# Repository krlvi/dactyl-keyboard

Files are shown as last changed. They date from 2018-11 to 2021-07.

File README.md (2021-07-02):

lfkdsj
# Dactyl Marshmallow
The Dactyl is a parameterized, split-hand, concave, columnar, ergonomic keyboard, originally written by Matt Adereth. See [his README](https://github.com/adereth/dactyl-keyboard#readme) for general info. Here's what's different about mine:

* Round, marshmallowy sides and bottom, in contrast to adereth's minimalist squarish shape.
* (In theory) more configurability, like for different numbers of rows and columns. The thumb is still kind of hardcoded, and there are still hacks.

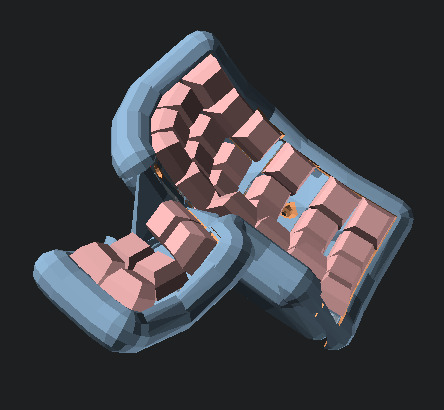
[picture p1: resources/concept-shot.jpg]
A rendering of the whole keyboard, assembled


## Making one of your own

The keyboard is written as a Clojure program, which emits OpenSCAD
code, and as some lower-level OpenSCAD code. Unlike in the original
repository, I don't tend to keep the .scad and .stl files emitted by
the program in the repository and downloadable. Maybe once I get to
1.0.

### Setting up a build environment

* [Install the Clojure runtime](https://clojure.org)
* [Install the Leiningen project manager](http://leiningen.org/)
* [Install OpenSCAD](http://www.openscad.org/)
* Clone https://github.com/adereth/unicode-math; `lein install` it so you have version 0.2.1 ready.

### Building the design

* Run `lein repl`
* Load the file `(load-file "src/dactyl_keyboard/dactyl.clj")`
* This will generate the `things/*.scad` files
* In the `things` directory, `make -k -j8` (it is a GNU makefile). This will build the `.stl` files - and take a half an hour, likely.

### Iterating

* Have an `.scad` file open in OpenSCAD.
* Have this command running: `sh editloop.sh --no-fstl src/dactyl_keyboard/dactyl.clj dactyl-blank-all`
* Make changes to the design, save files, watch as everything is rerun.

There are faster things you can do (keep the REPL open, and do the
`(load-file)` again), and nicer things (CIDER), but this way works for
me and I left it at that.

You can change the definitions of `skip-tags` and `emit-tags` in
`dactyl.clj` to avoid creating some outputs. This can save time if you
are iterating on a part and not the whole keyboard. The keywords you
can put in are just below, in `make-filename`. For example, to avoid
emitting the left half, change the definition of `skip-tags` to:

```
(def skip-tags #{:left})
```

### Printing

Filename convention:

```
[object]-[lr]-[part][piece].stl

e.g.
dm-l-bot01.stl
```

`dm` stands for Dactyl Marshmallow. `lr` is `l` for the left hand, `r`
for the right. Parts are `bot` for bottom, `sid` for sides, `fra` for
frame, and `screw-hole-top`. File names are short so you can tell them
apart on a small LCD display such as you may have on your 3D
printer. There may not be `.stl` files for every numbered piece of the
`bot` part; this is ok. Print one of each piece, and ten
screw-hole-tops. (Don't print `debug-*` files.)  Print also a
`teensy-holder-a` and a `teensy-holder-b`.

Put your controller into the holder, put the two holder pieces
together, and contrive to hold them that way, likely by gluing, but
maybe temporarily with a rubber band. You may not want to stick the
controller in permanently until after you've soldered the wires onto
it.

Numbered pieces of each `dm` part should be glued together. To glue
the bottom, tie pieces together with fishing line, and hold tight
while applying Sci-Grip 4 (acrylic weld, with dichloromethane, danger,
read safety directions) or liquid cyanoacrylate. To glue the frame,
use spring clamps while applying very thin glue such as the foregoing.

Press threaded inserts into the ten screw hole tops using a soldering
iron. Then glue them onto the waffly bits on top of the `bot`
part. Glue the legs on the bottom.

Press a threaded insert into the screw hole in the bottom of one of
the frame pieces. This is where the `teensy-holder` screws in.

Install the connectors into the sides pieces. The USB extension just
screws on; the RJ-11... who knows. Glue?

Once you've installed keyswitches into the frame, done your wiring,
and soldered the wires to the controller, you can screw the frame to
the bottom. Then maybe it's a good time to glue the sides on. Figure
out how you are going to get the last piece in place with all the
other ones already glued, before you start gluing.

This is how I imagine it all goes together. I've still never gotten
all the pieces printed yet! I keep making little changes.

## License

Copyright © 2015, 2018 Matthew Adereth and Jared Jennings

The source code for generating the models (everything excluding the [things/](things/) and [resources/](resources/) directories is distributed under the [GNU AFFERO GENERAL PUBLIC LICENSE Version 3](LICENSE).  The generated models and PCB designs are distributed under the [Creative Commons Attribution-ShareAlike License Version 4.0](LICENSE-models).

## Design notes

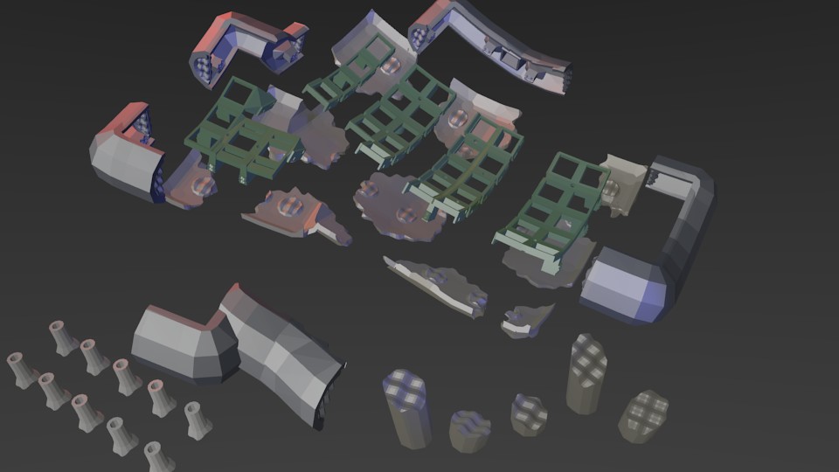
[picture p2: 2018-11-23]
resources/pieces.jpg

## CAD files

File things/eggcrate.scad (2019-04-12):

/** Points of a plane, to which the +x axis is normal
    sy, sz: number of samples in y and z directions.
    dy, dz: size of samples in y and z directions, in units.
    x_offset: location of troughs, in units.
 */
function x_grid_points(sy, sz, dy, dz, x_offset) =
     [for(z=[0:1:sz], y=[0:1:sy])
               [x_offset, y*dy, z*dz]];

/** Points of a wobbly plane, to which the +x axis is normal.
    sy, sz: number of samples in y and z directions.
    dy, dz: size of samples in y and z directions, in units.
    fy, fz: frequency of sine functions in y and z directions -
            given in units, not in samples.
    py, pz: phase in y and z directions - units not samples.
    x_offset: location of midpoint of waves, in units.
    amplitude: depth from peak to trough, in units.
*/
function x_eggcrate_points(sy, sz, dy, dz, fy, fz, py, pz,
                            x_offset, amplitude) =
     [for(z=[0:1:sz], y=[0:1:sy])
               [x_offset+amplitude/4*(0+ /* 2 if you want troughs at 0 */
                                    sin((y*dy+py)*fy*360)+
                                    sin((z*dz+pz)*fz*360)),
                y*dy,
                z*dz]];

/* maybe this *_a, *_b stuff is weak sauce, but i don't know how to
   generate two triangles at a time and end up with a list of [[a1,
   b1, c1], [a2, b2, c2], [a3, b3, c3]] and not some other crazy shape
   which would not work right. for a bit i had [[a1, b1, c1, a2, b2,
   c2], [a3, b3, c3, a4, b4, c4]] and i assume some of those were not
   planar. openscad segfaulted somewhere in cgal's nef_3 module.
   https://github.com/CGAL/cgal/issues/3309
   https://github.com/openscad/openscad/issues/2464
*/

/** Point indices into a grid/eggcrate points vector
    which will result in a series of triangles facing +x.
    The a triangles are only half of them.
    sy, sz: number of samples in y and z directions.
*/
function x_grid_faces_a(sy, sz) =
     [for(z=[0:1:sz-1], y=[0:1:sy-1])
               [y+1+(z+0)*(sy+1),
                y+0+(z+0)*(sy+1),
                y+0+(z+1)*(sy+1)]];

/** Point indices into a grid/eggcrate points vector
    which will result in a series of triangles facing +x.
    The b triangles are only half of them.
    sy, sz: number of samples in y and z directions.
*/
function x_grid_faces_b(sy, sz) =
     [for(z=[0:1:sz-1], y=[0:1:sy-1])
               [y+1+(z+0)*(sy+1),
                y+0+(z+1)*(sy+1),
                y+1+(z+1)*(sy+1)]];

/** Point indices into a grid/eggcrate points vector,
    which will result in a series of triangles facing -x.
    The a triangles are only half of them.
    sy, sz: number of samples in y and z directions.
*/
function minusx_grid_faces_a(sy, sz) =
     [for(z=[0:1:sz-1], y=[0:1:sy-1])
               [y+0+(z+1)*(sy+1),
                y+0+(z+0)*(sy+1),
                y+1+(z+0)*(sy+1)]];


/** Point indices into a grid/eggcrate points vector,
    which will result in a series of triangles facing -x.
    The b triangles are only half of them.
    sy, sz: number of samples in y and z directions.
*/
function minusx_grid_faces_b(sy, sz) =
     [for(z=[0:1:sz-1], y=[0:1:sy-1])
                    [y+1+(z+1)*(sy+1),
                     y+0+(z+1)*(sy+1),
                     y+1+(z+0)*(sy+1)]];

/** Point indices into a pair of grid points vectors concatenated,
    which will result in a series of triangles connecting the two grids.
    Facing -z, +y, +z, -y, respectively.
    The a triangles are only half of them.
    sy, sz: number of samples in y and z directions.
*/
function x_box_edge_faces_a(sy, sz) =
     concat(
          /* the bottom (-z side) */
          [for(y=[0:1:sy-1], z=[0:1:0])
                    [y+0+(z+0)*(sy+1)+1*(sy+1)*(sz+1),
                     y+0+(z+0)*(sy+1)+0*(sy+1)*(sz+1),
                     y+1+(z+0)*(sy+1)+0*(sy+1)*(sz+1)]],
          /* the back (+y side) */
          [for(y=[sy:1:sy], z=[0:1:sz-1])
                    [y+0+(z+0)*(sy+1)+1*(sy+1)*(sz+1),
                     y+0+(z+0)*(sy+1)+0*(sy+1)*(sz+1),
                     y+0+(z+1)*(sy+1)+0*(sy+1)*(sz+1)]],
          /* the top (+z side) */
          [for(y=[0:1:sy-1], z=[sz:1:sz])
                    [y+1+(z+0)*(sy+1)+0*(sy+1)*(sz+1),
                     y+0+(z+0)*(sy+1)+0*(sy+1)*(sz+1),
                     y+0+(z+0)*(sy+1)+1*(sy+1)*(sz+1)]],
          /* the front (-y side) */
          [for(y=[0:1:0], z=[0:1:sz-1])
                    [y+0+(z+0)*(sy+1)+0*(sy+1)*(sz+1),
                     y+0+(z+0)*(sy+1)+1*(sy+1)*(sz+1),
                     y+0+(z+1)*(sy+1)+0*(sy+1)*(sz+1)]]);

/** Point indices into a pair of grid points vectors concatenated,
    which will result in a series of triangles connecting the two grids.
    Facing -z, +y, +z, -y, respectively.
    The b triangles are only half of them.
    sy, sz: number of samples in y and z directions.
*/
function x_box_edge_faces_b(sy, sz) =
     concat(
          /* the bottom (-z side) */
          [for(y=[0:1:sy-1], z=[0:1:0])
                    [y+1+(z+0)*(sy+1)+1*(sy+1)*(sz+1),
                     y+0+(z+0)*(sy+1)+1*(sy+1)*(sz+1),
                     y+1+(z+0)*(sy+1)+0*(sy+1)*(sz+1)]],
          /* the back (+y side) */
          [for(y=[sy:1:sy], z=[0:1:sz-1])
                    [y+0+(z+1)*(sy+1)+1*(sy+1)*(sz+1),
                     y+0+(z+0)*(sy+1)+1*(sy+1)*(sz+1),
                     y+0+(z+1)*(sy+1)+0*(sy+1)*(sz+1)]],
          /* the top (+z side) */
          [for(y=[0:1:sy-1], z=[sz:1:sz])
                    [y+1+(z+0)*(sy+1)+0*(sy+1)*(sz+1),
                     y+0+(z+0)*(sy+1)+1*(sy+1)*(sz+1),
                     y+1+(z+0)*(sy+1)+1*(sy+1)*(sz+1)]],
          /* the front (-y side) */
          [for(y=[0:1:0], z=[0:1:sz-1])
                    [y+0+(z+0)*(sy+1)+1*(sy+1)*(sz+1),
                     y+0+(z+1)*(sy+1)+1*(sy+1)*(sz+1),
                     y+0+(z+1)*(sy+1)+0*(sy+1)*(sz+1)]]);







function face_off(faces, off) =
     [for(f=faces) [for(v=f) v+off]];

module x_single_eggcrate_box(size, sample_size, frequency, amplitude,
                             phase=[0,0,0]) {
     sy = floor(size.y / sample_size.y);
     sz = floor(size.z / sample_size.z);
     plus_x_points = x_eggcrate_points(sy, sz,
                                       sample_size.y, sample_size.z,
                                       frequency.y, frequency.z,
                                       phase.y, phase.z,
                                       0, amplitude);
     minus_x_points = x_grid_points(sy, sz,
                                    sample_size.y, sample_size.z,
                                    -size.x);
     gf = concat(x_grid_faces_a(sy, sz), x_grid_faces_b(sy, sz));
     bgf = concat(minusx_grid_faces_a(sy, sz),
                  minusx_grid_faces_b(sy, sz));
     bef = concat(x_box_edge_faces_a(sy, sz),
                  x_box_edge_faces_b(sy, sz));
     polyhedron(points=concat(plus_x_points, minus_x_points),
                faces=concat(gf, bef, face_off(bgf, (sy+1)*(sz+1))),
          convexity=ceil(size.y*frequency.y + size.z*frequency.z)*2 );
}

/* this one mates with the x_single_eggcrate_box.
   it is up to you to translate it to get a glue tolerance. */
module x_mating_single_eggcrate_box(size, sample_size, frequency, amplitude,
                                    phase=[0,0,0]) {
     sy = floor(size.y / sample_size.y);
     sz = floor(size.z / sample_size.z);
     plus_x_points = x_grid_points(sy, sz,
                                   sample_size.y, sample_size.z,
                                   size.x);
     minus_x_points = x_eggcrate_points(sy, sz,
                                       sample_size.y, sample_size.z,
                                       frequency.y, frequency.z,
                                       phase.y, phase.z,
                                       0, amplitude);
     gf = concat(x_grid_faces_a(sy, sz), x_grid_faces_b(sy, sz));
     bgf = concat(minusx_grid_faces_a(sy, sz),
                  minusx_grid_faces_b(sy, sz));
     bef = concat(x_box_edge_faces_a(sy, sz),
                  x_box_edge_faces_b(sy, sz));
     polyhedron(points=concat(plus_x_points, minus_x_points),
                faces=concat(gf, bef, face_off(bgf, (sy+1)*(sz+1))),
          convexity=ceil(size.y*frequency.y + size.z*frequency.z)*2 );
}
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

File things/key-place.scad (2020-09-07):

/*
--- BEGIN AGPLv3-preamble ---
Dactyl Marshmallow ergonomic keyboard generator
Copyright (C) 2015, 2018 Matthew Adereth and Jared Jennings

This program is free software: you can redistribute it and/or modify
it under the terms of the GNU Affero General Public License as published by
the Free Software Foundation, either version 3 of the License, or
(at your option) any later version.

This program is distributed in the hope that it will be useful,
but WITHOUT ANY WARRANTY; without even the implied warranty of
MERCHANTABILITY or FITNESS FOR A PARTICULAR PURPOSE.  See the
GNU Affero General Public License for more details.

You should have received a copy of the GNU Affero General Public License
along with this program.  If not, see <http://www.gnu.org/licenses/>.
--- END AGPLv3-preamble ---
*/
/*
*/

tau = 360; // openscad works in degrees not radians

// placement
bet = tau / 48;
tenting_angle = tau / 8;
thu_alp = tau / 30;
thu_bet = tau / 8;
// switch_hole
keyswitch_height = 14.0;
keyswitch_width = 14.0;
cherry_bezel_width = 2.0;
mount_width = keyswitch_width + 2*cherry_bezel_width;
mount_height = keyswitch_height + 2*cherry_bezel_width;
sa_profile_key_height = 12.7;
these_blank_keycaps_i_got_from_ebay_height = 11.5;
key_height = these_blank_keycaps_i_got_from_ebay_height;
plate_thickness = 4;
web_thickness = 3.5;
// placement
cap_top_height = plate_thickness + key_height;
// things added to mount_width and mount_height here and below are
// kluges. to derive them, start with 0.0, subtract if there is
// distance between the closest switch holes, add if they overlap, and
// hope the keys with non-minimal distance between them don't end up
// too far apart to reach with your fingers.
column_radius = cap_top_height + ( ((mount_width + 1.8) / 2) / sin(bet/2) );
thu_row_radius = cap_top_height + ( ((mount_height + 1/2) / 2) / sin(thu_alp/2) );
thu_column_radius = cap_top_height + ( ((mount_width + 1.5) / 2) / sin(thu_bet/2) );
// connectors
post_size = 0.1;

// this is a function not an array because occasionally we may deal in
// half-columns, can't remember where
function ColumnOffset(column) = ((column >= 2) && (column < 3) ? [-0.5, 5.82, -5.0] : (column >= 5) ? [0, -12.8, 5.64] : (column >= 4) ? [0, -8.8, 5.64] : [0,0,0]);

module KeyPlace(col, row) {
     row_alphas = [ tau/16, tau/24, tau/18, tau/13, tau/12, tau/12 ];
     // must be >= 1.0. related somehow to the lengths of your fingers.
     column_radius_factors = [ 1.05, 1.05, 1.12, 1.03, 1.0, 1.0, 1.0 ];
     // this is to bring the number row closer without rotating its
     // keytops to such a rakish angle
     row_compensation = [ [0,-3,2], [0,0,0], [0,0,0], [0,0,0], [0,2,0], [0,2,0] ];
     alp = row_alphas[max(floor(row),0)];
     row_radius = (cap_top_height + ( ((mount_height + -1.0) / 2) / sin(alp/2) )) * column_radius_factors[max(floor(col),0)];
     column_angle = bet * (2 - col);
     column_splay = [0, 0, 4, 6, 11, 11];
     column_splay_radius = 30; // this has an interplay with the
                               // measure added to mount_width above
                               // in column_radius
     translate([0, 0, 44])
	  rotate(a=tenting_angle, v=[0,1,0])
          translate(ColumnOffset(col))
          translate([0, 0, column_radius])
          rotate(a=column_angle, v=[0, 1, 0])
          translate([0, 0, -column_radius])
          translate([0, -column_splay_radius, 0])
          rotate(a=-column_splay[max(floor(col),0)], v=[0,0,1])
          translate([0, column_splay_radius, 0])
          translate(row_compensation[max(floor(row),0)] *
                    pow(column_radius_factors[max(floor(col),0)],2))
          translate([0, 0, row_radius])
          rotate(a=alp*(2-row), v=[1,0,0])
          translate([0, 0, -row_radius])
          children();
}

module ThumbPlace(col, row) {
     thumb_column_splay = [6, 15, 22, 15, 15];
     thumb_column_splay_radius = 12; // this has an interplay with the
                               // measure added to mount_width above
                               // in column_radius
     thumb_column_y_compensation = [0, -4, -14, -6, -6];
     translate([-6, -49, 50])
          rotate(a=tau/10, v=[0,0,1])
          rotate(a=-tau/8, v=[0,1,0])
          translate([mount_width, 0, 0])
          translate([0, 0, thu_column_radius])
          rotate(a=col*thu_bet, v=[0,1,0])
          translate([0, 0, -thu_column_radius])
          translate([0, -thumb_column_splay_radius, 0])
          translate([0, thumb_column_y_compensation[max(floor(col),0)], 0])
          rotate(a=thumb_column_splay[max(floor(col),0)], v=[0,0,1])
          translate([0, thumb_column_splay_radius, 0])
          translate([0, 0, thu_row_radius])
          rotate(a=row*thu_alp, v=[1,0,0])
          translate([0, 0, -thu_row_radius])
          children();
}


module WebPost() {
     translate ([0, 0, (plate_thickness - (web_thickness/2))]) {
          cube ([post_size, post_size, web_thickness], center=true);
     }
}

/* the multiplier here makes the post tall enough that when you take
   the difference of something that sticks up off of the web with
   structures made out of hulls of this post, no detritus will be left
   over because it extended above these AboveWebPosts. Perhaps it
   should not be hitched to web_thickness. Oh well. */
module AboveWebPost() {
     translate ([0, 0, (plate_thickness + (web_thickness*5/2))]) {
          cube ([post_size, post_size, web_thickness*5], center=true);
     }
}

module WebLogHBW() {
     translate ([-web_thickness/2, 0, (plate_thickness - web_thickness)])
          cube ([web_thickness, post_size, post_size], center=true);
}
module WebLogHBE() {
     translate ([web_thickness/2, 0, (plate_thickness - web_thickness)])
          cube ([web_thickness, post_size, post_size], center=true);
}
module WebLogHTW() {
     translate ([-web_thickness/2, 0, plate_thickness])
          cube ([web_thickness, post_size, post_size], center=true);
}
module WebLogHTE() {
     translate ([web_thickness/2, 0, plate_thickness])
          cube ([web_thickness, post_size, post_size], center=true);
}

module WebLogVBN() {
     translate ([0, web_thickness/2, (plate_thickness - web_thickness)])
          cube ([post_size, web_thickness, post_size], center=true);
}
module WebLogVBS() {
     translate ([0, -web_thickness/2, (plate_thickness - web_thickness)])
          cube ([post_size, web_thickness, post_size], center=true);
}
module WebLogVTN() {
     translate ([0, web_thickness/2, plate_thickness])
          cube ([post_size, web_thickness, post_size], center=true);
}
module WebLogVTS() {
     translate ([0, -web_thickness/2, plate_thickness])
          cube ([post_size, web_thickness, post_size], center=true);
}


module Marker(x) {
     children();
}

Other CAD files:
things/teensy-holder-a.scad
things/teensy-holder-b.scad
renders/pieces.blend
renders/whole.blend
things/teensy-holder.scad
things/test_egghex2.scad

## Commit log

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2018-01-01 strengthen glue joints
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2018-02-04 make minktest shape smaller, to prepare for printing
    [dactyl-bottom-left-with-teensy.stl, dactyl-bottom-left.stl, dactyl-bottom-right.stl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]
2018-02-04 add minktest outputs, for easier printing
    [minktest-00.scad, minktest-00.stl, minktest-01.scad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]
2018-02-06 add third minktest object
    [minktest-02.scad, minktest-02.stl]
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2018-02-17 add rendered minktest object (these days)
    [minktest-00.scad, minktest-00.stl]
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2018-02-20 upload a render for web viewability
    [dactyl-blank-all.stl]
2018-02-24 Replace rotated cubes with hexagonal cones
    The rotated cubes ended up with some sides parallel to the axis along
    which the pieces fit together. When the print with pin-tolerance 0.5
    wiggled, in a fit of pique I set pin-tolerance to 0.01. Then some of
    these sides of the rotated cubes didn't fit inside each other - think of
    trying to stack a perfectly cubical freezer box inside another of the
    same size - and the remaining surfaces allowed the pieces to slide
    against each other. I'm afraid none of these words make sense until
    after you are holding the pieces of plastic; it certainly didn't to me
    before it was printed.
    Anyway the replacement is a hexagonal cone. This should make sliding
    impossi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
2018-03-12 add a mini layout in an attempt to make the change-compile-render loop faster; layout still hardcoded in some marshmallowy-sides functions
    [dactyl-blank-all.stl, minktest-00.scad, minktest-01.scad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]
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2018-03-29 fix bugs in generalization of half circle connectors; split out pin block
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2018-04-01 on the precipice of abolishing hollow pins
    Hollow pins were supposed to save plastic (and print time) where it
    wasn't needed: at the ends of marshmallowy sides pieces. But now I'm
    trying to make sides connectors, which will connect the marshmallowy
    sides pieces to the frame of the keyboard. To do this, I need to hull a
    piece of the side to the hole block. If the hole block has a
    half-cylindrical surface at its rear, that's quite easy. If the hole
    block is just a wafer, hulling it with something will fill in the holes.
    Maybe I won't get rid of hollow pins and wafer holes but they're going
    to be redefined completely, and this commit is a savegame before that
    happens.
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2018-04-01 apply kailh fix from FSund; switch back to y-and-b layout
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2018-04-25 fix a bug where coordinates intended for thumb-place were being passed to the key-place function, screwing up the bottom finger-edge-prism
2018-04-25 Move key-place out of Clojure into OpenSCAD.
    I've manually translated key-place to OpenSCAD; the result, KeyPlace, is
    in key-place.scad. I've added to scad-clj a facility for producing a
    call to a module including parameters and a block; this facility is
    required for this revision to work. In .../dactyl-keyboard, make a
    directory called checkouts. In that directory, clone my scad-clj from
    https://github.com/jaredjennings/scad-clj, and checkout the
    add-module-calls branch. You'll probably need to lein install, and you
    may or may not need to remove some cached stuff; I found and removed
    this by trial and error.
    The end result is that the SCAD code goes from 53MB to 3MB. I think that
    if module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
    [key-place.scad]
2018-04-26 scad-ify thumb-place, saving 500k of output scad code size
    [key-place.scad]
2018-04-27 write web-post in SCAD; define a module for mallowy-sides-right; requires scad-clj a2e4bb0
    [key-place.scad]
2018-04-28 use pairwise hull rather than minkowski for sides
    Now that the sides are built on a shape constructed by hulling together
    a bunch of key-placed primitives, there is no reason to make a ribbon
    and then minkowski a sphere along it; instead of hulling together
    web-posts and then doing something expensive with them, we could just
    hull together spheres instead. That's what this change does.
    It doesn't end up all that much faster, nor does it make smaller SCAD
    code, but the resultant shape looks simpler and nicer.
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2018-05-03 use subsets of big marshmallow to attach connectors
    Previously, the half-circle connectors were hulled to intersections of
    the entire big marshmallow sides object with a sliver. This required
    mentioning the entire big marshmallow sides object multiple times, which
    made the size of the OpenSCAD output balloon, and even after a module
    was defined for the object, it still made OpenSCAD's CPU and memory
    usage too high.
    With this change, we create the part of the marshmallowy sides near to
    each connector, and use that for intersection instead, only mentioning
    the entire marshmallowy sides object when unioning the half-circle
    connectors onto it.
2018-05-03 fix poor connection with hole piece
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2018-05-11 raise keyboard into positive z (closes #9)
    [key-place.scad]
2018-05-21 Make the switch hole slightly smaller.
    The constants here call for a 14.4mm x 14.4mm switch hole. I measured
    one of my actual printed switch holes at something like 14.1mm. My
    switches (Kailh Brown) fall out of these holes. An acrylic switch tester
    I got from NovelKeys, into which my switches fit nice and tightly, has a
    13.7mm hole height. So I'm reducing the switch hole size to 14.0mm. The
    difference between what's written here and what's printed doesn't
    concern me a great deal: the difference is made up by layers that sag a
    little, stringy bits from insufficient filament retraction, and other
    byproducts of an imperfect physical process. I'm just trying to make it
    so as many of the switch h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
2018-05-27 Split bottom cover into pieces (closes #8)
    It's nifty how I did this, and this approach came after a lengthy detour
    into rhombic dodecahedra, and the honeycomb constructed from them,
    turned out to be a dead end. The hexagonal prisms offered here don't cut
    sharp angles into the pieces, and the zigzag added over the Z-axis,
    combined with the curve of the cover, should offer some keying so that
    the pieces aren't quite free to slide along the Z-axis when being glued.
    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
    [vertical-prisms.scad]
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2018-05-28 add a profusion of screw holes in the frame (#4)
    Maybe not all of these are needed. I wonder if they weaken the structure
    by any material amount, and if screws that are on sides of keys not
    corners will interfere with the keycaps.
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2018-06-02 the 14.0mm switch hole was too small; bump up to 14.2 (was 14.4)
2018-06-03 make shear in vertical-prisms a named constant
    [vertical-prisms.scad]
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2018-06-09 change the keyswitch size where it matters, in key-place.scad
    [key-place.scad]
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2018-06-22 Replace north and south sides-connector-frame (closes #17)
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2018-06-24 fix mismatch between end of sides piece and sides-sides connector
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2018-06-26 add a couple of Blender scenes; show keyboard pieces
    [pieces.blend, whole.blend]
2018-06-26 try 14.0mm switch holes
    [key-place.scad]
2018-06-28 fix teensy bracket, kind of (#6)
2018-07-06 add Teensy holder (#6); screw tab may be too thick
    [teensy-holder-a.scad, teensy-holder-b.scad, teensy-holder.scad]
2018-07-07 move teensy holder to be centered on screw hole (#6)
    [teensy-holder.scad]
2018-07-07 move teensy holder down so top of screw hole is at z=0 (#6)
    [teensy-holder.scad]
2018-07-07 cut off bottom of overmold surround; it will likely not fit inside the keyboard (#6)
    [teensy-holder.scad]
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2018-07-07 replace teensy retainer bracket with screw hole for teensy holder (closes #6)
2018-07-11 add clearance check model to make sure teensy holder will fit
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2018-07-12 remove minktest outputs from version control
    [minktest-00.scad, minktest-00.stl, minktest-01.scad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]
2018-07-12 remove a couple of output files that are no longer output
    [dactyl-blank-all.scad, dactyl-blank-all.stl]
2018-07-12 Add AGPLv3 preambles to pertinent files.
    Since I've now written some parts of this in OpenSCAD, and I haven't
    really split the manually-written OpenSCAD source code from that which
    is generated, the simple statements in the README are no longer
    completely unambiguous. These preambles are. I've applied them with
    https://github.com/jaredjennings/apply-preambles, so they'll all be the
    same, and it should be easy to make your editor fold them up.
    [key-place.scad, teensy-holder-a.scad, teensy-holder-b.scad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]
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2018-07-13 make vertical prisms wider (#29)
    [vertical-prisms.scad]
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2018-07-20 add legs (with no glue tolerance)
2018-07-20 add glue tolerance to legs
2018-07-23 add epsilons so leg waffles will come out right
    [vertical-prisms.scad]
2018-07-23 add capability for holes, to lace pieces together when gluing (#29)
    [vertical-prisms.scad]
2018-07-23 tweak teensy holder dimensions so it fits my real teensy lc
    This is one iteration past what I have actually printed and stuck the board in. It may be too loose.
    [teensy-holder.scad]
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2018-08-21 slice a bit off of half-circle connectors (fixes #40, fixes #41)
2018-09-08 fix a copy-paste bug in the legs dating to 7898f325 (Jul 20)
2018-09-08 add working single and double eggcrate primitives
    [eggcrate.scad]
2018-09-08 stop crashing openscad; add string holes; add iterator
    [eggcrate.scad]
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2018-09-08 use eggcrate splitters for legs
    [eggcrate.scad]
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2018-09-08 remove vertical-prisms scad module, not used anymore in favor of eggcrate
    [vertical-prisms.scad]
2018-09-10 shorten output filenames
    I sometimes print files via SD card, and the printer's display for
    filenames is only so long. With whole words in the filename, like
    dactyl-sides-right02.scad, when choosing among multiple files on the SD
    card, I see something like "dactyl-sid" or so. So here we shorten names
    of output files so they will be distinguishable.
2018-09-10 redo concept shot with the present leg-based bottom
    [whole.blend]
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2018-09-15 move holes closer to eggcrate (#48)
    [eggcrate.scad]
2018-09-15 smaller bottom pieces (print took too long); change bottom piece offset (sight unseen) (#48)
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2018-09-24 begin eggcrate hexagonal prisms. hours of wrestling already.
    [egghex.scad]
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2018-09-26 add hex_prism_of_grid.
    waves was a bad idea and should be removed in favor of res. the prisms
    have gone all wonky where module four is used instead of three; this
    needs fixed.
    [egghex2.scad]
2018-09-26 fix wonky prisms. waves still needs to be removed
    [egghex2.scad]
2018-09-27 use egghex splitters to split keyboard bottom (wip)
    [egghex2.scad]
2018-09-27 maybe fix last column of polys; unify egghex2 with eggcrate
    [egghex2.scad]
2018-09-28 close up last column of triangles in the hex prism in a way symmetrical with the other sides
    [egghex2.scad]
2018-09-28 make proper top and bottom caps for what turns out to be a not-quite-strictly-hexagonal prism
    [egghex2.scad]
2018-09-28 make hex prism stop having degenerate polygons; now renderable
    [egghex2.scad]
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2018-10-01 fix bug that made egghex-split pieces not fit together; split out tests
    [egghex2.scad, test_egghex2.scad]
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2018-11-23 fix bottom material in pieces shot
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2019-03-25 lower amplitude of split waves drastically; less glue tolerance
    [egghex2.scad, test_egghex2.scad]
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2019-04-12 fix some OpenSCAD warnings
    [eggcrate.scad]
2019-04-12 Revert "round off edges of frame glue joints"
    It made STLs that Slic3r couldn't make any sense of.
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2019-05-18 Go back to the future: import the intermediate STL
    To time it the new way, and to stay, so we don't have to think about
    what the bottom is shaped like with CGAL any more than once.
    This reverts commit 83408ed92e23bb540488d943aadac7287afd6e05.
2019-06-17 replace lace holes with clamp surfaces
    [egghex2.scad]
2019-06-17 Revert "replace lace holes with clamp surfaces"
    This reverts commit edf6556a395370075b7989946537670b61f3aa23.
    Problems with clamp surfaces as implemented: (1) they are not normal to
    the surface being split, but to the xy plane. This means the clamping
    surface is sloped relative to the clamp, and clamping will not work. (2)
    they indiscriminately fill in features on the surface intended for
    gluing things onto. The idea was to sand these clamp surfaces off, but
    you can't sand it off of a little wavy screw hole connector. (3) there
    was too much clamp surface below the thing to be clamped and not enough
    above. Easy fix, but why bother in view of the two other problems?
    [egghex2.scad]
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2020-04-15 splay columns, so the keys farthest from the user's arm are wider apart
    [key-place.scad]
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2020-04-16 get rid of egghex splitters for bottom panel - eggcrate splitters for legs yet remain
    [egghex.scad, egghex2.scad]
2020-04-16 change the entire shape of the keyboard because i feel like it. untested!
    [key-place.scad]
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2020-06-11 completely redo key and thumb placement
    I got some wrist braces and found they seemed to work best with much
    more tenting than my default-settings Dactyl Manuform has. So I
    ratcheted up the tenting. Also I have positioned the thumb in what I
    hope is sort of a compromise between the original Dactyl and the
    Dactyl Manuform, and should enable thumb key chording easily.
    [key-place.scad]
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2020-07-05 raise beta; widen bezel; tweak for buildability
    It was always clear to me that along a column there should be a curve,
    because my fingers move in curves. But it was only recently that I
    read why there should be a curve across the row, when my fingers
    mostly push down, not out toward the sides of my hand: it is a
    compromise to place keys closer together, made possible because
    keycaps are narrower at the top. Accordingly in this changeset we
    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
    [key-place.scad]
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2020-09-07 set screw holes into web, so screw heads will land properly
    [key-place.scad]
2020-09-07 correct above-web shape at switch holes
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2020-09-07 put bottom definition back to normal; make it build properly
    [key-place.scad]
2020-09-09 bore out screw insert bosses better; fix some thumb problems in sides and bottom
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
